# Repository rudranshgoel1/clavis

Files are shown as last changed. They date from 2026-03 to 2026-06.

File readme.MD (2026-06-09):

# Clavis


### Why did I make it?
I have always did software, and I wanted to dip my hands in hardware, so my first project was actually a USB Hub, but I was too lazy to submit that project and ofcourse too lazy to do this also, but I need a keyboard badly, so I made it instead of spending money to buy one.

### What was the hardest part about this ?
First time trying hardware and its actually interesting, I lowkey ditched software so hard, I haven't touched anything for the past week or so.
Really fun doing hardware not gonna lie!

Features:

- RotaryEncoder for Volume Control
- 61 keys
- Raspberry Pi Pico
- Customised layout
- KMK firmware
- Clavis Branded PCB
- Custom case

### Schematic
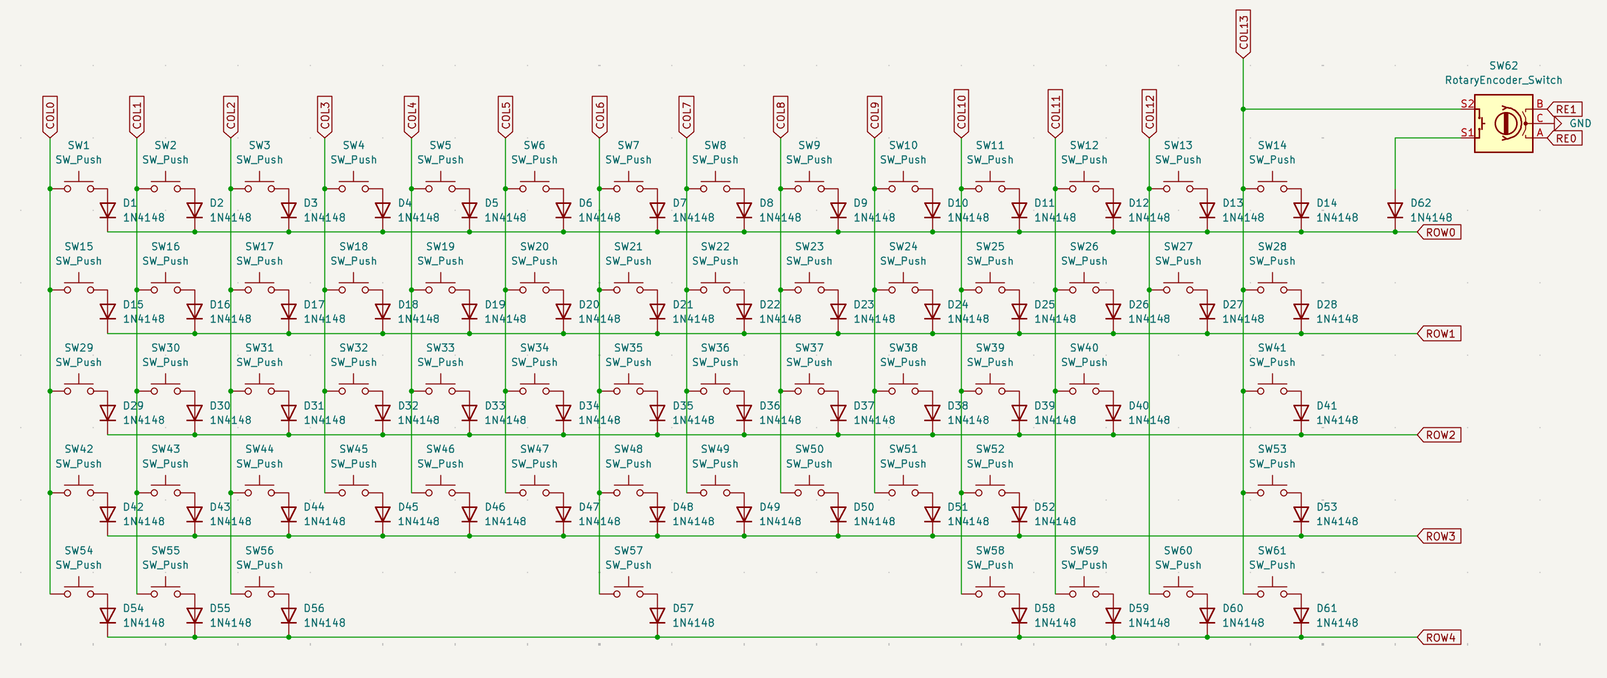
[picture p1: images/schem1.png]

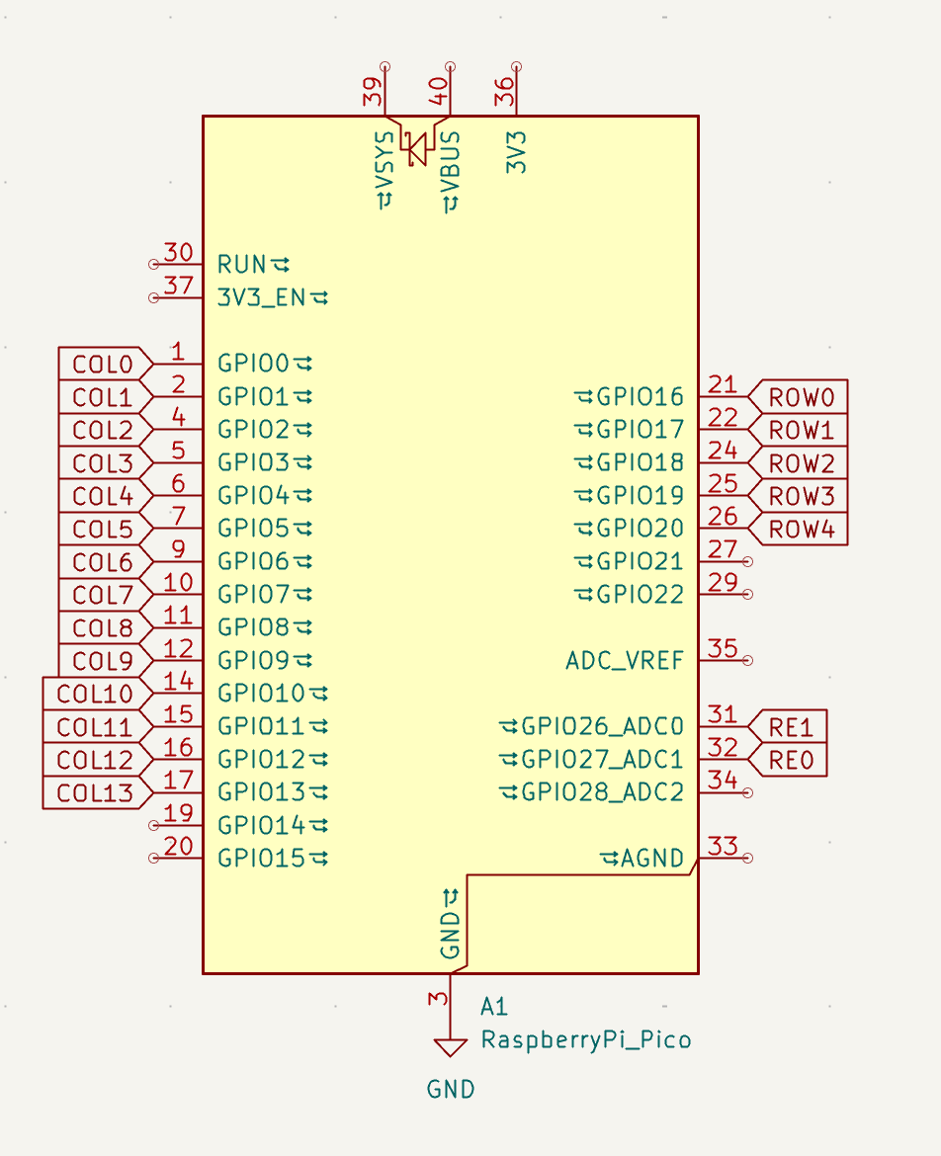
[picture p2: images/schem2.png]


### PCB 
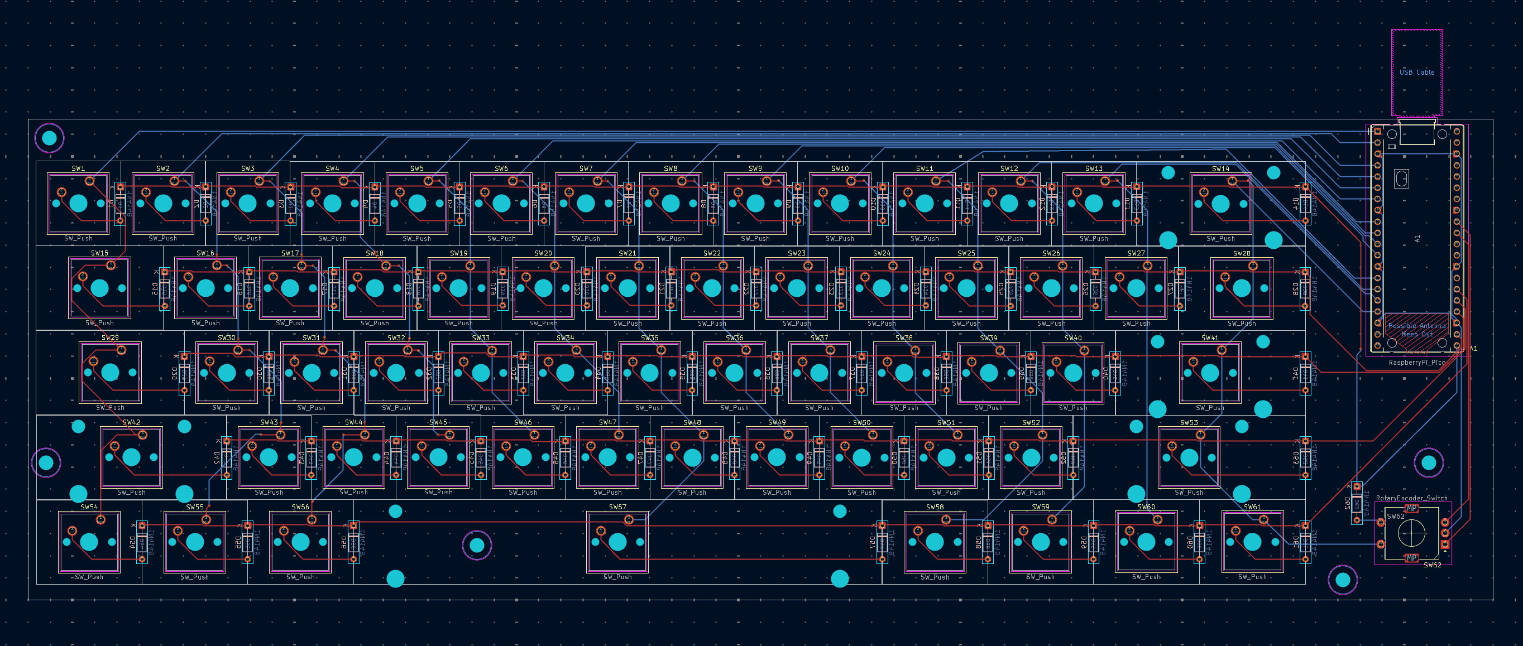
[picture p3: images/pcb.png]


### Case




- Side


I made some aesthetic for Clavis. Like I have added holes on all the sides to make it look more good

### 3D view of all parts 
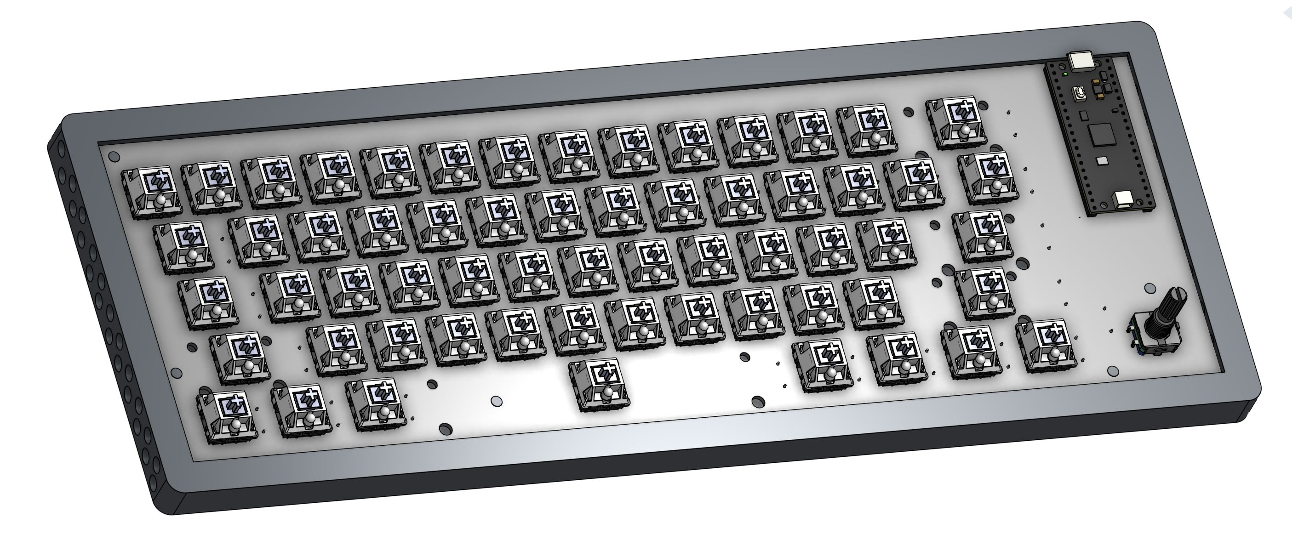
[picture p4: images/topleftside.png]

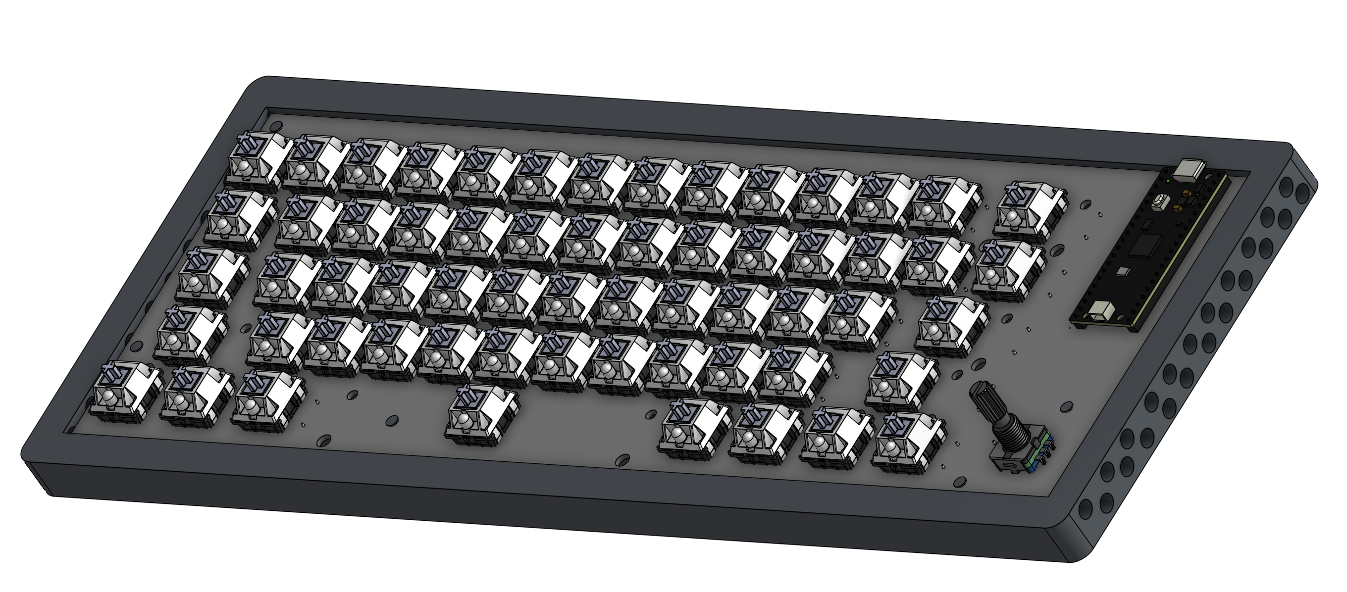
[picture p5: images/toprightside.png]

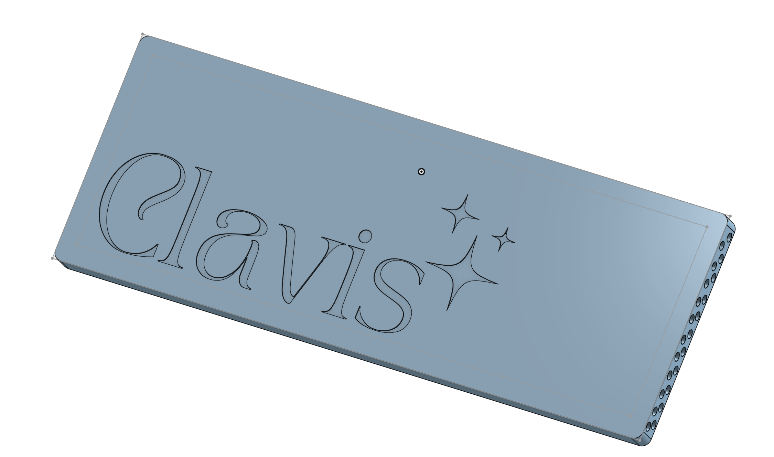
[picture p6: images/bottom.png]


link to full 3d thing-
https://cad.onshape.com/documents/4ed86aec979a191abbaea04f/w/0de3f3de07dd510f46e22fad/e/19a866b01119f1b2fa2c9c33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

A special thanks to Anay and Aditya who are helping me to make my projects better. Love them so much!

## BOM
|Name |Purpose |Quantity|Total Cost (USD)|Link |Distributor |
|---|---|---|---|---|---|
|Akko Mirror Switch |Switches for the keyboard |61 |21.24 |https://stackskb.com/store/akko-mirror-switch-pack-of-45-pre-order/ |StacksKB |
|Veekos Gradient Keycaps (Cherry Profile) (135 keys) (Blue) |Keycaps for the keyboard |1 |13.90 |https://stackskb.com/store/veekos-gradient-keycaps-cherry-profile-135-keys/ |StacksKB |
|Durock Smokey Screw-In Stabilizers V2 (4+1 w/ 6.25u spacebar)|Stabilizers for longer keys |1 |17.00 |https://stackskb.com/store/durock-smokey-screw-in-stabilizers-v2/ |StacksKB |
|EC11 Rotary Encoder with Switch |RotaryEncoder for Volume Control|1 |0.68 |https://www.flyrobo.in/15mm-ec11-rotary-encoder-with-switch-digital-potentiometer|Fly Robo |
|Diode 1N4148 Through - Hole |Diode for every switch |1 |1.08 |https://www.amazon.in/dp/B084ZP5BJ3?_encoding=UTF8&psc=1 |Amazon |
|Raspberry Pi Pico |Rasp Pi Pico as the MCU |1 |6.40 |https://www.amazon.in/Raspberry-Pi-Headers-Soldered-Micro/dp/B08WPNM7JB |Amazon |
|PCB |Main PCB of the keyboard |5 |27.47 |https://jlcpcb.com/ |JLPCB |
|M3 x 8mm Bolt |Screws |10 |1.73 |https://www.amazon.in/dp/B07X8PHXKB |Amazon |
|M3 Nuts |Screws |12 |0.79 |https://www.amazon.in/dp/B09J92WY5Q |Amazon |
|M3 x 5mm Heatset Insert |Screws |25 |2.09 |https://www.amazon.in/dp/B0CX1BS7DJ |Amazon |
|Soldering Iron Kit |Soldering Iron Kit |1 |5.26 |https://www.amazon.in/dp/B0FC2YM1RY |Amazon |
|Case |Shipping - Case for the keyboard|1 |5.00 | |Printing Legion|

## Shipping
Amazon + StacksKB = ~$2
Printing Legion = ~$5

Total Shipping = $7

## Total Pricing
The total price comes out to be 9,166 INR ($97.64)
Total Shipping = $7

The pricing might slightly vary due to flash sales, and dollar market trends.

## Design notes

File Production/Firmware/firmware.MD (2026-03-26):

## Flashing and Configuring the Keyboard

Steps to install the firmware and configure the keyboard:

### 1. Downloading the Repository
Download or clone this repository to your computer.
https://github.com/rudranshgoel1/clavis.git

### 2. Enter Boot Mode on the Pico
1. Unplug the Raspberry Pi Pico from your computer.
2. Hold down the **BOOTSEL** button on the Pico.
3. While holding the button, plug the Pico into your computer using a USB cable.
4. The computer will detect a new drive named **RPI-RP2**.

### 3. Flash CircuitPython
1. Download the latest CircuitPython `.uf2` for the Raspberry Pi Pico from [circuitpython.org](https://circuitpython.org/board/raspberry_pi_pico/).
2. Drag and drop the `.uf2` file onto the **RPI-RP2** drive.

Once the file finishes copying, the Pico will reboot automatically and appear as a new drive named **CIRCUITPY**.

### 4. Install KMK and the Keymap
1. Download KMK from [kmkfw.io](https://kmkfw.io) and copy the `kmk/` folder to the root of **CIRCUITPY**.
2. Copy `main.py` from this repository to the root of **CIRCUITPY**.

Your drive should look like this:
```
CIRCUITPY/
├── main.py
└── kmk/
```

### 5. Configure the Keymap
The keyboard layout can be customised in `main.py`.

Open the file in a text editor and edit the keymap section to match the layout you want.
After saving the file, the keyboard will automatically reload with the new configuration.

### 6. Test the Keyboard
Unplug and reconnect the keyboard, open a text editor, and press some keys to make sure everything works.

## KABOOM!
IT'S DONE!!!

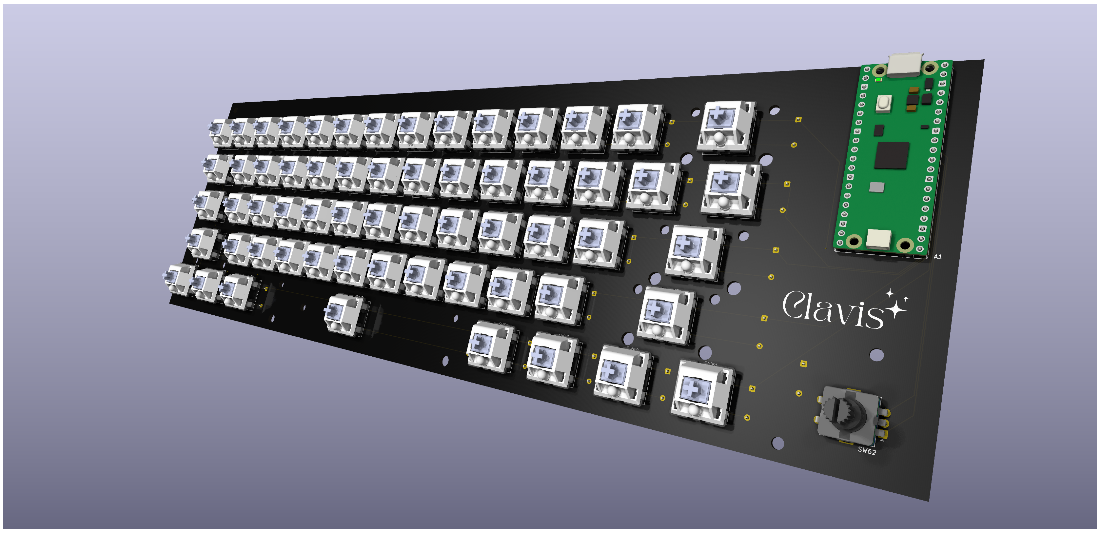
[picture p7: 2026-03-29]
PCB/images/sideview.png

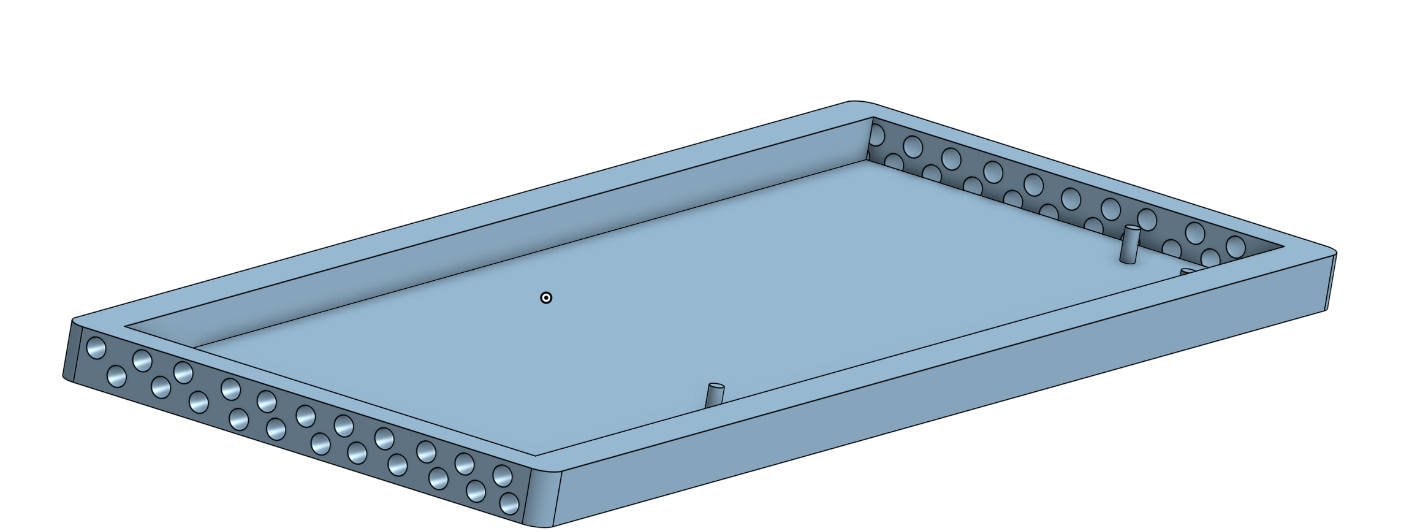
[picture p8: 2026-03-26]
images/left_side.png

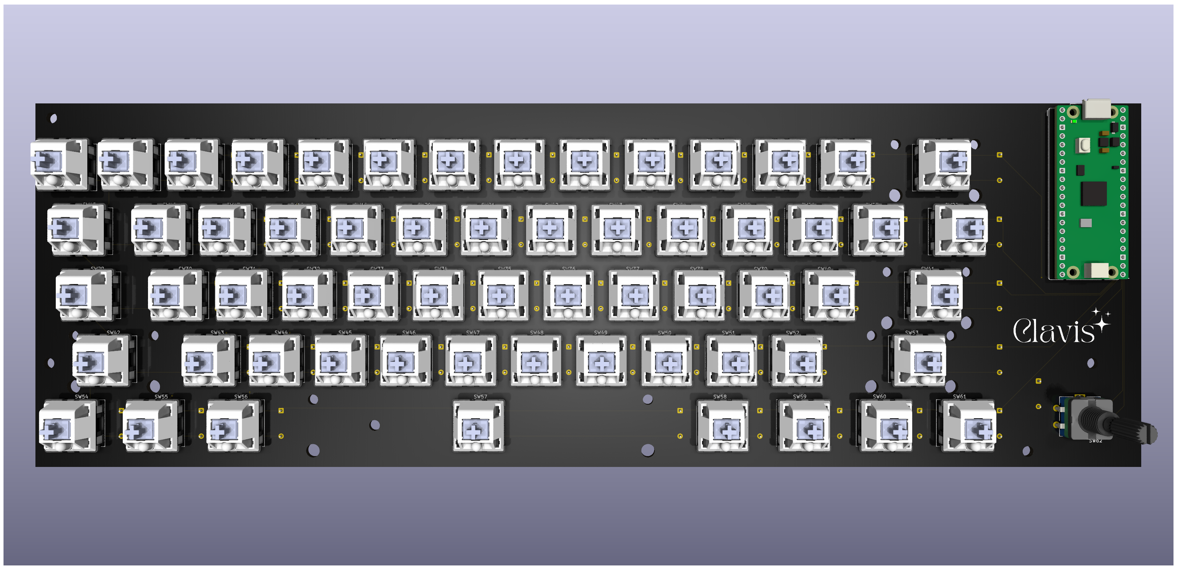
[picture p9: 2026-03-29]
images/topview.png

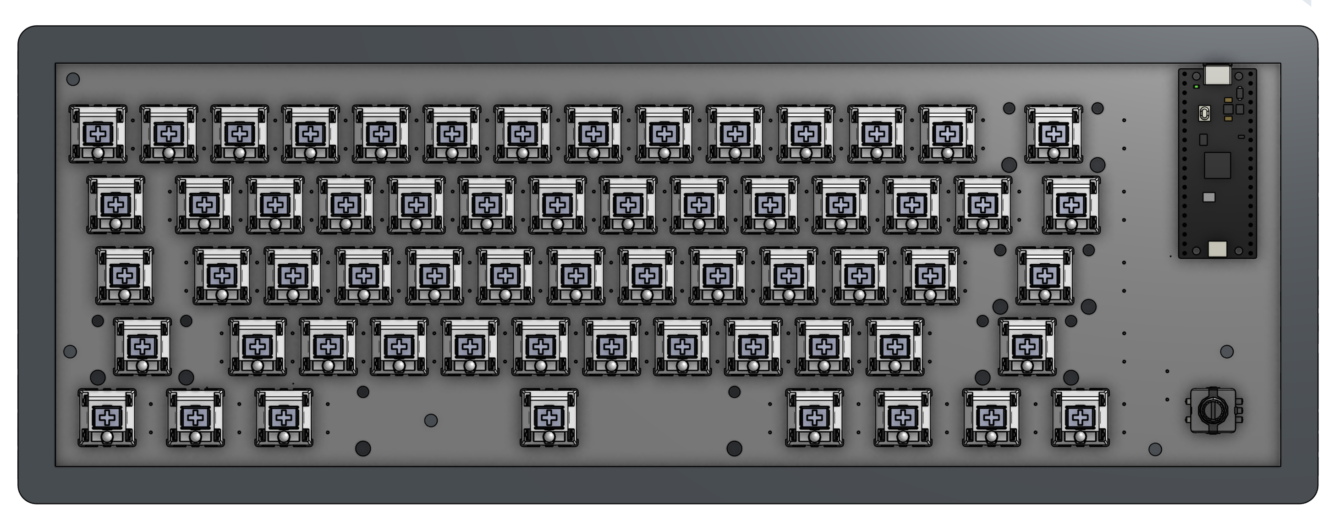
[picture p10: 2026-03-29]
images/topviewpcb.png

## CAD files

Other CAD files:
Production/CAD/Full Keyboard Assembly.step
CAD/Case/Clavis_Case.step
Production/CAD/Case/Clavis_Case.step
CAD/Case/Clavis_Case.stl
Production/CAD/Case/Clavis_Case.stl

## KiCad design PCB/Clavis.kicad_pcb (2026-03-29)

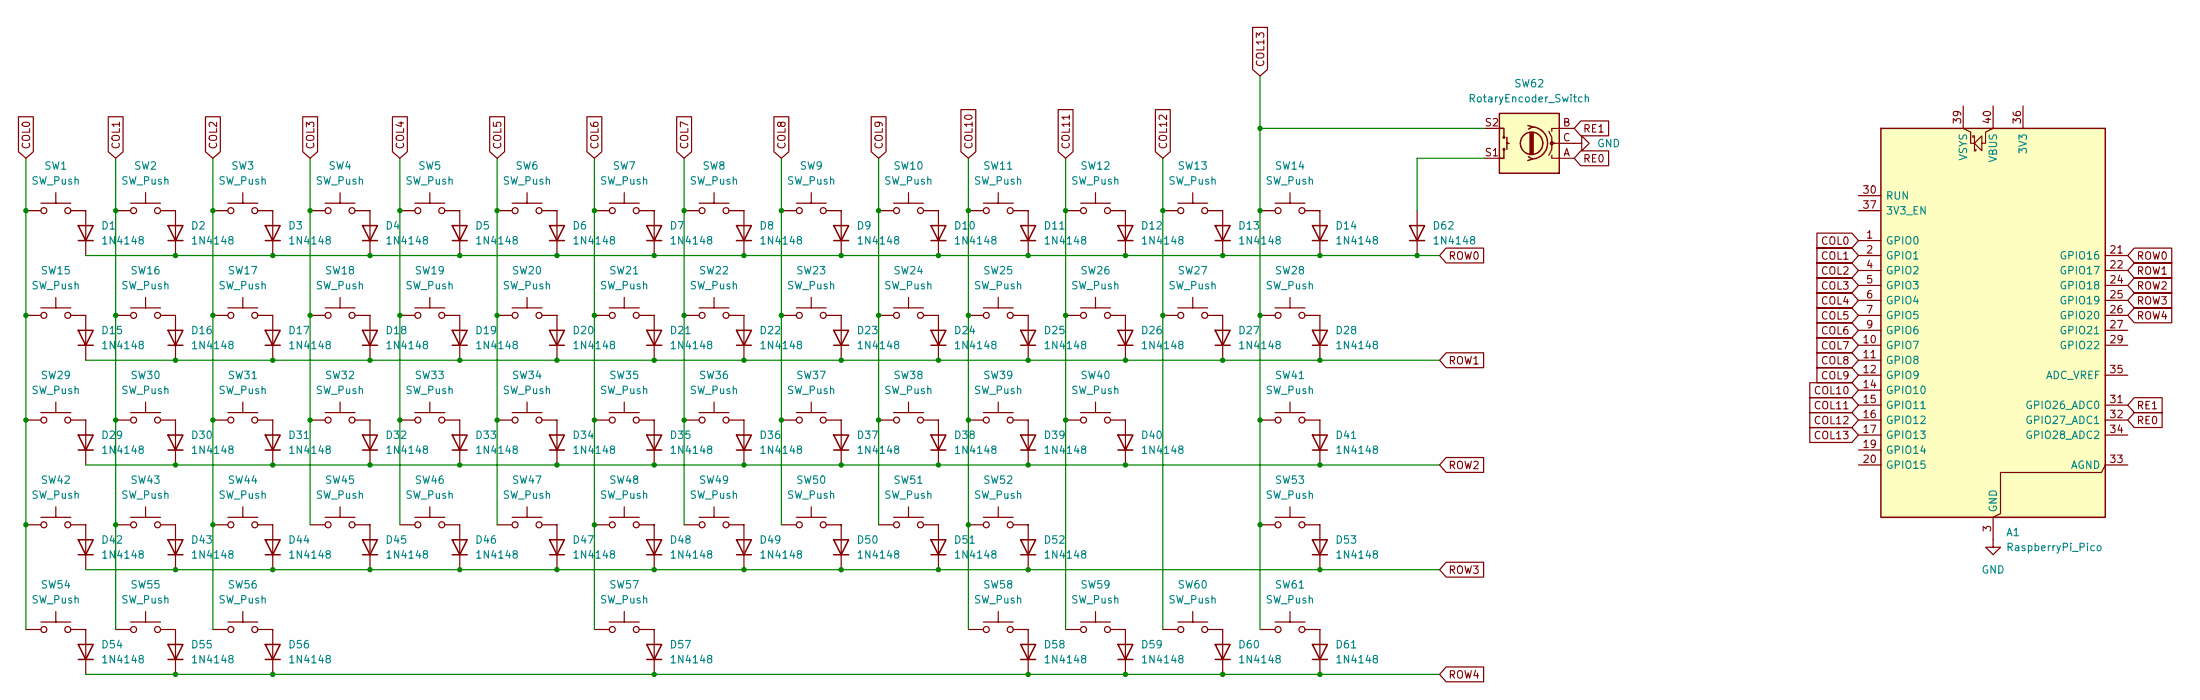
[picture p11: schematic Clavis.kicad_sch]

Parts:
A1: RaspberryPi_Pico; RaspberryPi_Pico_Common_THT
D1, D2, D3, D4, D5, D6, D7, D8, D9, D10, D11, D12, D13, D14, D15, D16, D17, D18, D19, D20, D21, D22, D23, D24, D25, D26, D27, D28, D29, D30, D31, D32, D33, D34, D35, D36, D37, D38, D39, D40, D41, D42, D43, D44, D45, D46, D47, D48, D49, D50, D51, D52, D53, D54, D55, D56, D57, D58, D59, D60, D61, D62: 1N4148; D_DO-35_SOD27_P7.62mm_Horizontal
SW1, SW2, SW3, SW4, SW5, SW6, SW7, SW8, SW9, SW10, SW11, SW12, SW13, SW16, SW17, SW18, SW19, SW20, SW21, SW22, SW23, SW24, SW25, SW26, SW27, SW30, SW31, SW32, SW33, SW34, SW35, SW36, SW37, SW38, SW39, SW40, SW43, SW44, SW45, SW46, SW47, SW48, SW49, SW50, SW51, SW52: SW_Push; SW_Cherry_MX_1.00u_PCB
SW14: SW_Push; SW_Cherry_MX_2.00u_PCB
SW15, SW28: SW_Push; SW_Cherry_MX_1.50u_PCB
SW29: SW_Push; SW_Cherry_MX_1.75u_PCB
SW41, SW42: SW_Push; SW_Cherry_MX_2.25u_PCB
SW53: SW_Push; SW_Cherry_MX_2.75u_PCB
SW54, SW55, SW56, SW58, SW59, SW60, SW61: SW_Push; SW_Cherry_MX_1.25u_PCB
SW57: SW_Push; SW_Cherry_MX_6.25u_PCB
SW62: RotaryEncoder_Switch; RotaryEncoder_Alps_EC11E-Switch_Vertical_H20mm

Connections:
COL0: A1.1 (GPIO0), SW1.1, SW15.1, SW29.1, SW42.1, SW54.1
COL1: A1.2 (GPIO1), SW2.1, SW16.1, SW30.1, SW43.1, SW55.1
COL2: A1.4 (GPIO2), SW3.1, SW17.1, SW31.1, SW44.1, SW56.1
COL3: A1.5 (GPIO3), SW4.1, SW18.1, SW32.1, SW45.1
COL4: A1.6 (GPIO4), SW5.1, SW19.1, SW33.1, SW46.1
COL5: A1.7 (GPIO5), SW6.1, SW20.1, SW34.1, SW47.1
COL6: A1.9 (GPIO6), SW7.1, SW21.1, SW35.1, SW48.1, SW57.1
COL7: A1.10 (GPIO7), SW8.1, SW22.1, SW36.1, SW49.1
COL8: A1.11 (GPIO8), SW9.1, SW23.1, SW37.1, SW50.1
COL9: A1.12 (GPIO9), SW10.1, SW24.1, SW38.1, SW51.1
COL10: A1.14 (GPIO10), SW11.1, SW25.1, SW39.1, SW52.1, SW58.1
COL11: A1.15 (GPIO11), SW12.1, SW26.1, SW40.1, SW59.1
COL12: A1.16 (GPIO12), SW13.1, SW27.1, SW60.1
COL13: A1.17 (GPIO13), SW14.1, SW28.1, SW41.1, SW53.1, SW61.1, SW62.S2
GND: A1.3 (GND), A1.8 (GND), A1.13 (GND), A1.18 (GND), A1.23 (GND), A1.28 (GND), A1.38 (GND), SW62.C
unnamed: D1.2 (A), SW1.2
unnamed: D2.2 (A), SW2.2
unnamed: D3.2 (A), SW3.2
unnamed: D4.2 (A), SW4.2
unnamed: D5.2 (A), SW5.2
unnamed: D6.2 (A), SW6.2
unnamed: D7.2 (A), SW7.2
unnamed: D8.2 (A), SW8.2
unnamed: D9.2 (A), SW9.2
unnamed: D10.2 (A), SW10.2
unnamed: D11.2 (A), SW11.2
unnamed: D12.2 (A), SW12.2
unnamed: D13.2 (A), SW13.2
unnamed: D14.2 (A), SW14.2
unnamed: D15.2 (A), SW15.2
unnamed: D16.2 (A), SW16.2
unnamed: D17.2 (A), SW17.2
unnamed: D18.2 (A), SW18.2
unnamed: D19.2 (A), SW19.2
unnamed: D20.2 (A), SW20.2
unnamed: D21.2 (A), SW21.2
unnamed: D22.2 (A), SW22.2
unnamed: D23.2 (A), SW23.2
unnamed: D24.2 (A), SW24.2
unnamed: D25.2 (A), SW25.2
unnamed: D26.2 (A), SW26.2
unnamed: D27.2 (A), SW27.2
unnamed: D28.2 (A), SW28.2
unnamed: D29.2 (A), SW29.2
unnamed: D30.2 (A), SW30.2
unnamed: D31.2 (A), SW31.2
unnamed: D32.2 (A), SW32.2
unnamed: D33.2 (A), SW33.2
unnamed: D34.2 (A), SW34.2
unnamed: D35.2 (A), SW35.2
unnamed: D36.2 (A), SW36.2
unnamed: D37.2 (A), SW37.2
unnamed: D38.2 (A), SW38.2
unnamed: D39.2 (A), SW39.2
unnamed: D40.2 (A), SW40.2
unnamed: D41.2 (A), SW41.2
unnamed: D42.2 (A), SW42.2
unnamed: D43.2 (A), SW43.2
unnamed: D44.2 (A), SW44.2
unnamed: D45.2 (A), SW45.2
unnamed: D46.2 (A), SW46.2
unnamed: D47.2 (A), SW47.2
unnamed: D48.2 (A), SW48.2
unnamed: D49.2 (A), SW49.2
unnamed: D50.2 (A), SW50.2
unnamed: D51.2 (A), SW51.2
unnamed: D52.2 (A), SW52.2
unnamed: D53.2 (A), SW53.2
unnamed: D54.2 (A), SW54.2
unnamed: D55.2 (A), SW55.2
unnamed: D56.2 (A), SW56.2
unnamed: D57.2 (A), SW57.2
unnamed: D58.2 (A), SW58.2
unnamed: D59.2 (A), SW59.2
unnamed: D60.2 (A), SW60.2
unnamed: D61.2 (A), SW61.2
unnamed: D62.2 (A), SW62.S1
RE0: A1.32 (GPIO27_ADC1), SW62.A
RE1: A1.31 (GPIO26_ADC0), SW62.B
ROW0: A1.21 (GPIO16), D1.1 (K), D2.1 (K), D3.1 (K), D4.1 (K), D5.1 (K), D6.1 (K), D7.1 (K), D8.1 (K), D9.1 (K), D10.1 (K), D11.1 (K), D12.1 (K), D13.1 (K), D14.1 (K), D62.1 (K)
ROW1: A1.22 (GPIO17), D15.1 (K), D16.1 (K), D17.1 (K), D18.1 (K), D19.1 (K), D20.1 (K), D21.1 (K), D22.1 (K), D23.1 (K), D24.1 (K), D25.1 (K), D26.1 (K), D27.1 (K), D28.1 (K)
ROW2: A1.24 (GPIO18), D29.1 (K), D30.1 (K), D31.1 (K), D32.1 (K), D33.1 (K), D34.1 (K), D35.1 (K), D36.1 (K), D37.1 (K), D38.1 (K), D39.1 (K), D40.1 (K), D41.1 (K)
ROW3: A1.25 (GPIO19), D42.1 (K), D43.1 (K), D44.1 (K), D45.1 (K), D46.1 (K), D47.1 (K), D48.1 (K), D49.1 (K), D50.1 (K), D51.1 (K), D52.1 (K), D53.1 (K)
ROW4: A1.26 (GPIO20), D54.1 (K), D55.1 (K), D56.1 (K), D57.1 (K), D58.1 (K), D59.1 (K), D60.1 (K), D61.1 (K)

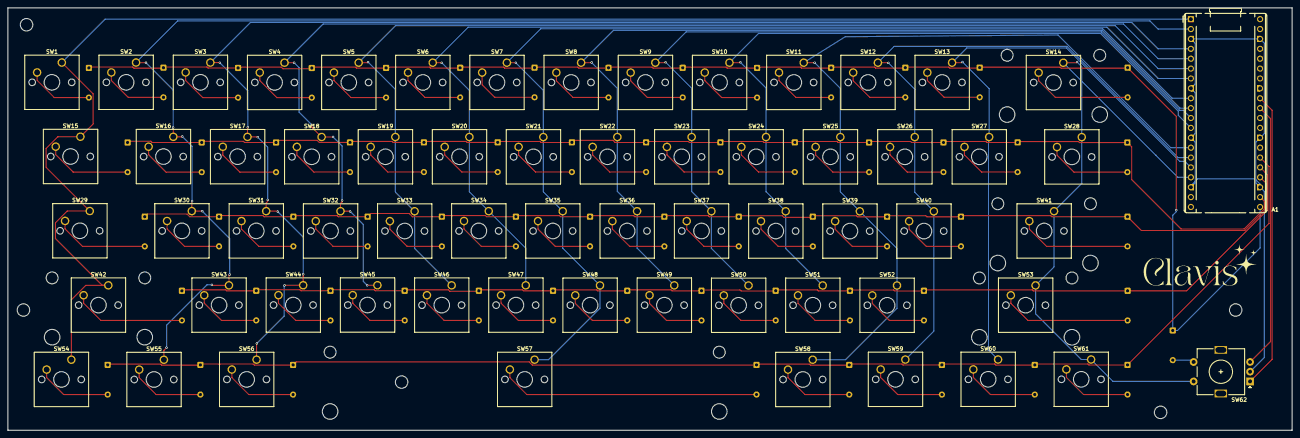
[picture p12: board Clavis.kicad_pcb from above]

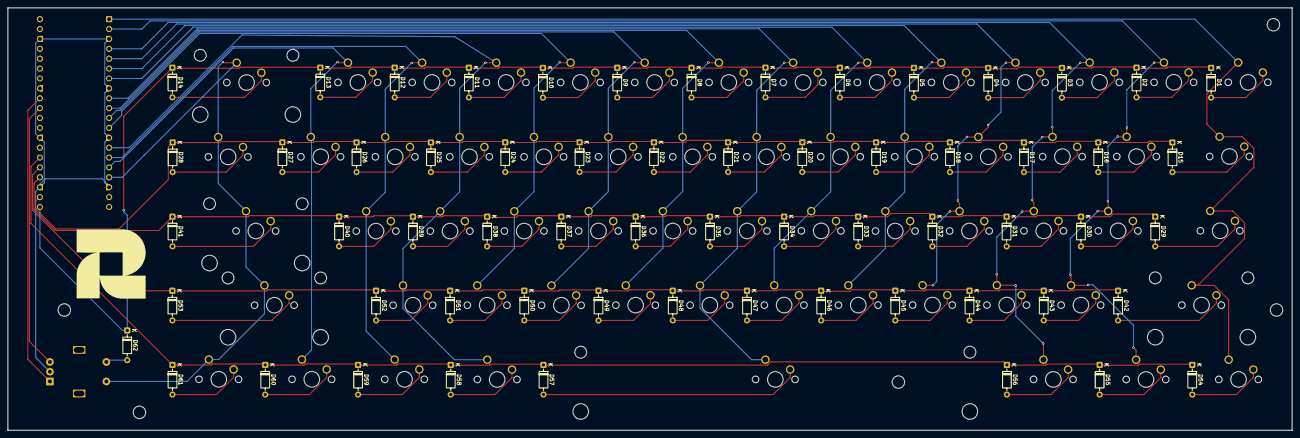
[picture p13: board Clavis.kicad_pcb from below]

Board: 2 copper layers, 330.0 x 108.5 mm, 125 parts (62 on the bottom side), 84 nets.

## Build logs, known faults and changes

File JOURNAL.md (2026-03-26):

<!--
  This journal is auto generated by Stasis.
-->

# 3/26/2026 9 PM - Making the Github Repo

_Time spent: 2.5h_

I finally made the entire github repo after so long, 
I made changes to the enitre firmware too. I changed from QMK to KMK, as QMK compiler was bugging and eventually I gave up. So after 12 crueling hours or so, my first actual completed hardware project is built omg. and it is ready to be shipped!!

Screenshot 2026-03-27 at 3.01.57 AM

Screenshot 2026-03-27 at 3.07.04 AM




# 3/24/2026 11 AM - Firmware

_Time spent: 1.5h_

Firmware has been successfully made. I used QMK for this. The matrix is 5x14 (5 Rows, 14 Columns).

Total 61 keys + 1 RotaryEncoder for Volume Control + switch of RotaryEncoder triggers the mute/unmute option.

Screenshot 2026-03-24 at 4.53.33 PM

Screenshot 2026-03-24 at 4.54.02 PM




# 3/23/2026 7 PM - Keyboard Case

_Time spent: 3h_

I made the case, I used to do 3d modelling way back in 2020 (in blender too), I forgot everything and now made the entire case in OnShape.

First time (technically) making a 3d model. it was fun ngl, but it is not fun with a trackpad. (P.S: I made this case **WITH** a *TRACKPAD*)

anyways, here is the case in the making:

Screenshot 2026-03-21 at 2.09.59 AM

Screenshot 2026-03-21 at 2.23.52 AM

and here is the case fully made:

Screenshot 2026-03-24 at 12.45.11 AM

Screenshot 2026-03-24 at 12.45.31 AM






# 3/23/2026 6 PM - Added a Rotary Encoder (forgot to journal)

_Time spent: 0.25h_

I added a rotary encoder for volume control, since the keyboard has no function keys and i wanna control the volume.

Screenshot 2026-03-24 at 12.22.53 AM

Screenshot 2026-03-24 at 12.23.22 AM

PCB :
Screenshot 2026-03-24 at 12.24.01 AM





# 3/20/2026 8 PM - PCB Routing

_Time spent: 2.5h_

Screenshot 2026-03-21 at 1.35.32 AM
Screenshot 2026-03-21 at 1.36.17 AM

I finally routed the PCB and added a RotaryEncoder for volume control, it was really stressy to do this, as this is my first time making a keyboard with 61 switches.

After this, I will make the case for the same and hopefully make it very good.




# 3/19/2026 7 PM - PCB Designing

_Time spent: 2h_

i made the pcb, not wiring yet, at first i put the diodes on the right side up, but then my friend said MIDWAY that it has to be on the opposite side, you CANNOT blame me, its literally 1AM. but yeah, i fixed it and designed the whole pcb, now it feels complete and all. now only the wiring is left, which i will do tomorow i think. anyway this is what the pcb looks till now: 

Screenshot 2026-03-20 at 1.03.20 AM

and the back side in 3d view:

Screenshot 2026-03-20 at 1.06.27 AM




# 3/19/2026 4 PM - Schematic

_Time spent: 1.5h_

I basically made the schematic of Clavis. It is a 60% keyboard, qwerty layout, first time making a keyboard overall.

Before wiring schematic looked like this:



And now, the schematic is finished and now looks like this:

Screenshot 2026-03-19 at 10.20.26 PM

I have also added the columns and rows to the pico:

Screenshot 2026-03-19 at 10.21.03 PM

Right now, I will be making the PCB for the same.





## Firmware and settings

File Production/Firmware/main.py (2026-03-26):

import board
from kmk.kmk_keyboard import KMKKeyboard
from kmk.keys import KC
from kmk.scanners.matrix import MatrixScanner, DiodeOrientation
from kmk.modules.encoder import EncoderHandler
from kmk.modules.layers import Layers

keyboard = KMKKeyboard()

keyboard.matrix = MatrixScanner(
    column_pins=(
        board.GP0,  board.GP1,  board.GP2,  board.GP3,
        board.GP4,  board.GP5,  board.GP6,  board.GP7,
        board.GP8,  board.GP9,  board.GP10, board.GP11,
        board.GP12, board.GP13,
    ),
    row_pins=(
        board.GP16, board.GP17, board.GP18, board.GP19, board.GP20,
    ),
    diode_orientation=DiodeOrientation.COL2ROW,
)

layers = Layers()

encoder_handler = EncoderHandler()
encoder_handler.pins = (
    (board.GP27, board.GP26, None, False),
)

keyboard.modules = [layers, encoder_handler]

_______ = KC.TRNS

keyboard.keymap = [

    [
        KC.ESC,  KC.N1,   KC.N2,   KC.N3,   KC.N4,   KC.N5,   KC.N6,   KC.N7,   KC.N8,   KC.N9,   KC.N0,   KC.MINS, KC.EQL,  KC.MUTE,
        KC.TAB,  KC.Q,    KC.W,    KC.E,    KC.R,    KC.T,    KC.Y,    KC.U,    KC.I,    KC.O,    KC.P,    KC.LBRC, KC.RBRC, KC.BSPC,
        KC.CAPS, KC.A,    KC.S,    KC.D,    KC.F,    KC.G,    KC.H,    KC.J,    KC.K,    KC.L,    KC.SCLN, KC.QUOT, KC.ENT,  KC.NO,
        KC.LSFT, KC.Z,    KC.X,    KC.C,    KC.V,    KC.B,    KC.N,    KC.M,    KC.COMM, KC.DOT,  KC.SLSH, KC.RSFT, KC.NO,   KC.NO,
        KC.LCTL, KC.LGUI, KC.LALT, KC.NO,   KC.NO,   KC.NO,   KC.NO,   KC.SPC,  KC.NO,   KC.RALT, KC.MO(1),KC.APP,  KC.RCTL, KC.NO,
    ],

    [
        KC.GRV,  KC.F1,   KC.F2,   KC.F3,   KC.F4,   KC.F5,   KC.F6,   KC.F7,   KC.F8,   KC.F9,   KC.F10,  KC.F11,  KC.F12,  KC.MUTE,
        _______, _______, _______, _______, _______, _______, _______, _______, _______, _______, KC.PSCR, KC.SLCK, KC.PAUS, KC.DEL,
        _______, _______, _______, _______, _______, _______, KC.LEFT, KC.DOWN, KC.UP,   KC.RGHT, _______, _______, _______, KC.NO,
        _______, _______, _______, _______, _______, _______, _______, KC.MUTE, KC.VOLD, KC.VOLU, _______, _______, KC.NO,   KC.NO,
        _______, _______, _______, KC.NO,   KC.NO,   KC.NO,   KC.NO,   _______, KC.NO,   _______, _______, _______, KC.RESET,KC.NO,
    ],
]

encoder_handler.map = [
    ((KC.VOLD, KC.VOLU),),   # Layer 0
    ((KC.MPRV, KC.MNXT),),   # Layer 1
]

if __name__ == '__main__':
    keyboard.go()

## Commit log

2026-03-26 main commit
    [BOM.csv, Base.stl, Clavis.kicad_pcb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]
2026-03-26 changed a few things
    [BOM.csv, Base.stl, Clavis Base.stl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]
2026-03-29 made some changes
    [BOM.csv, Clavis.kicad_pcb]
2026-03-31 Add STEP via LFS (fixed)
    [Full Keyboard Assembly.step]
2026-03-31 cad files
    [Clavis Base.stl, Clavis_Case.step, Clavis_Case.stl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]
